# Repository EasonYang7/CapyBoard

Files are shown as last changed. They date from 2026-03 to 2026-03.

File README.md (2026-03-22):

# CapyBoard

Capyboard is a custom designed 80% TKL with custom knobs & OLED screen to fuel the exciting daily workload!

Inspired from the cute Capybara, the keyboard is a cozy comfort to all students studying for exams, and locking in for academics :)

## Features:
- Top & Bottom 3D Modelled Case
- 1x 128x64 OLED Display
- 2x Rotary Knob
- 79x RGB LEDs
- 79x Keys
- KMK Support

## BOM:
- 79x Cherry MX Switches
- 79x SK6812 Mini LEDs
- 79x 1N4148 Diodes
- 1x 128x64 OLED Screen
- 2x 4.7k 0603 Resistors
- 2x EC11E Rotary Encoders
- 1x Seeed Studio Xiao
- 1x Raspberry Pi Pico
- 1x Keycap Set

## Microcontroller
This keyboard supports two microcontroller options:
- Seeed Studio Xiao RP2040 (Main Usage)
- Raspberry Pi Pico (Alternative Usage if Needed)

Both firmware files will be used for seperate input purposes

## Flashing Firmware:

### Step 1 - Install MicroPython
1. Hold BOOTSEL Button on XIAO, and plug in USB-C
2. Download MicroPython .uf2 from https://micropython.org/download/SEEED_XIAO_RP2040/
3. Drag and Drop .uf2 file into RPI-RP2 Drive

### Step 2 - Install KMK
1. Download KMK from https://github.com/KMKfw/kmk_firmware
2. Copy the kmk folder to my XIAO

**Step 3 - Flash Keyboard Firmware**
1. Copy XIAO_code.py to your XIAO and rename it main.py

## Assembly
- Solder components using the schematic as reference
- Install switches onto PCB
- 3D Print the Case
- Use M2 Screws to Assemble the Chassis
- Flash Firmware onto the Keyboard!

## Usage
- Plug USB-C Cable to the Seeed Xiao Studio RP2040
- Keys are Mapped, and can be Modified using KMK!

## Pictures
Schematics:



PCB:




3D Model:


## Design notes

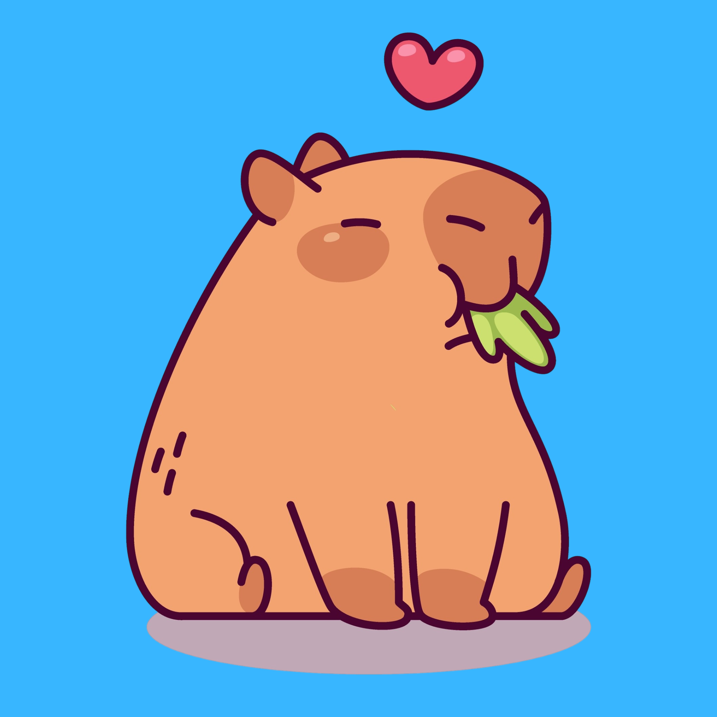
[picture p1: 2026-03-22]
pcb/assets/capybara.png

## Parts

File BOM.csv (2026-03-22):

Component | Quantity | Description | Price (USD) | Link
Seeed Xiao Studio RP2040 | 1 | Microcontroller | 4.68 | https://www.digikey.com/en/products/detail/seeed-technology-co-ltd/102010428/14672129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
Raspberry Pi Pico | 1 | Microcontroller | 4.00 | https://www.digikey.com/en/products/detail/raspberry-pi/SC0915/13624793
Switch | 90 (Cheapest Quantity) | MX Keyboard Switch | Current Price: 20.99 (Original Price: 23.52) | https://www.aliexpress.us/item/3256806239135691.html?curPageLogUid=KsPg7OFSwE63
LEDs | 100 (Cheapest Quantity) | SK6812 MINI-E | 4.33 | https://www.aliexpress.com/item/1005007863635868.html?curPageLogUid=sAzteVQnU8do
Diodes | 100 (Cheapest Quantity) | 1N4148 Diodes | 3.38 | https://www.digikey.com/en/products/detail/onsemi/1N4148/458603
OLED | 1 | 0.96in OLED | Current Price: 1.14 (Original Price: 5.35) | https://www.aliexpress.us/item/3256806076593949.html
Resistors | 10 (Cheapest Quantity) | 4.7k Resistors | 0.06 | https://www.digikey.com/en/products/detail/yageo/RC0603FR-074K7L/727212
Rotary Encoders | 2 | EC11E Rotary Encoders | 8.98 | https://www.digikey.com/en/products/detail/alps-alpine/EC11E09244BS/21721622
Keycap Set | 1 | Capybara Cherry PBT Set | Current Price: 27.12 (Original Price: 63.07) | https://www.aliexpress.us/item/3256809804692169.html?curPageLogUid=72wE0FsKHJUA
PCB | 1 | JLCPCB PCB Assembly | 24.50 (Estimate) | https://jlcpcb.com/

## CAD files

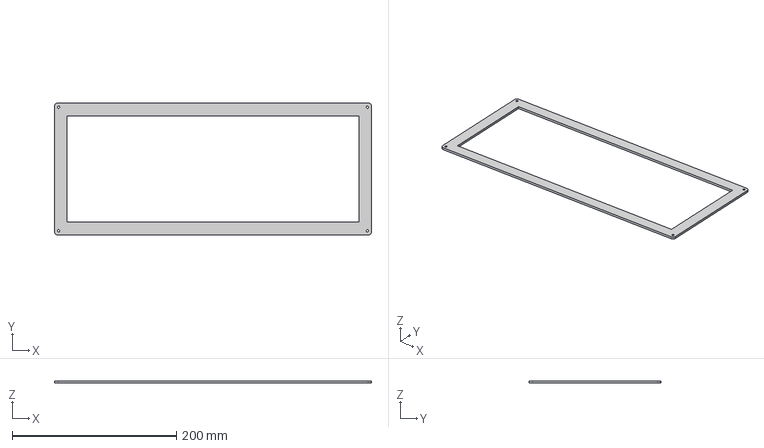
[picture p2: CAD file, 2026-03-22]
cad/CapyBoard Top.step
385.5 x 160.5 x 3.00 mm

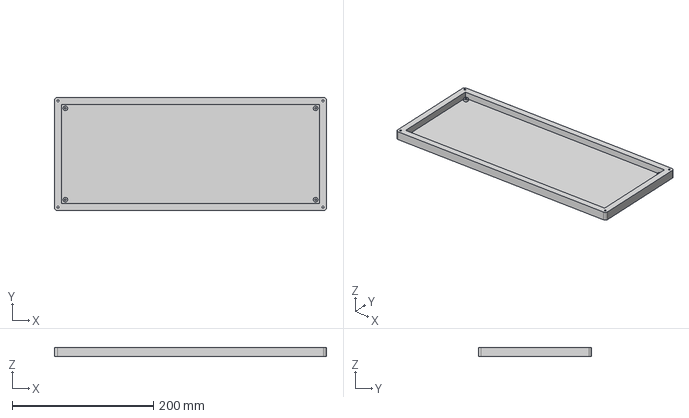
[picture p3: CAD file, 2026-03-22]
cad/CapyBoard Bottom.step
385.5 x 160.5 x 13.0 mm

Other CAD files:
cad/CapyBoard Bottom.f3d
cad/CapyBoard Top.f3d

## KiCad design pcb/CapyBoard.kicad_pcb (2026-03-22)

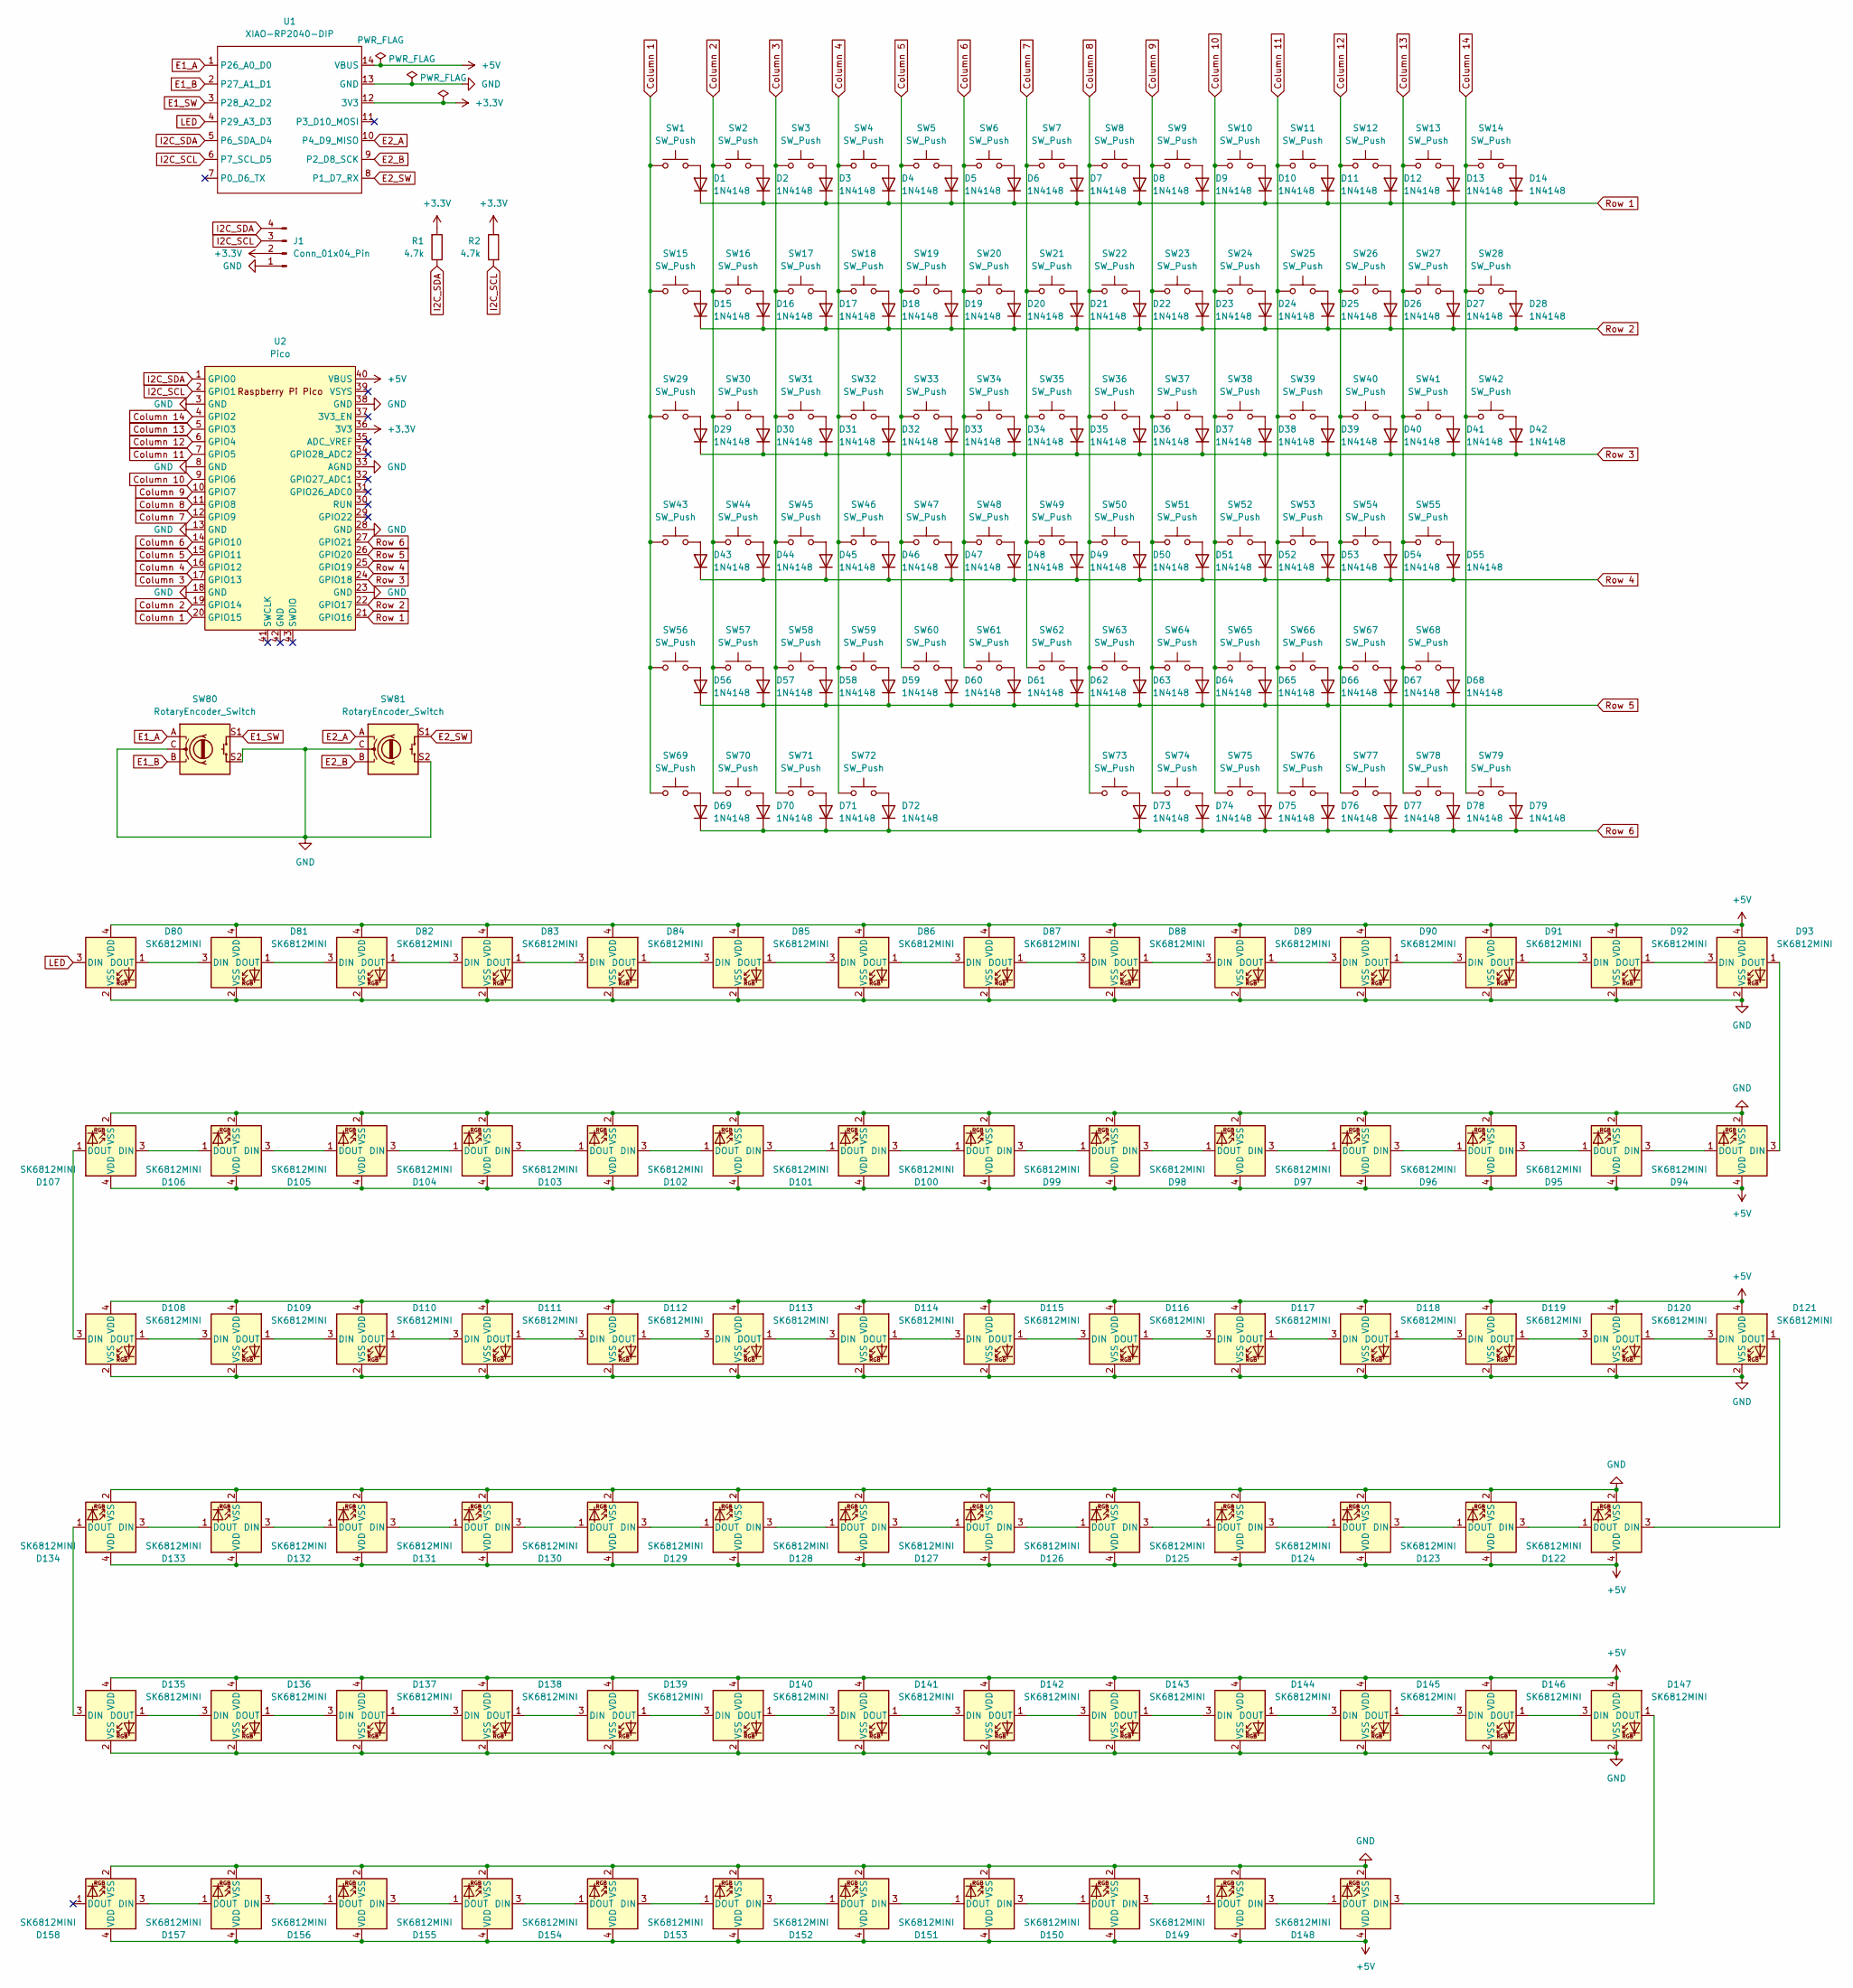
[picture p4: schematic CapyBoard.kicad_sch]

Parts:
D1, D2, D3, D4, D5, D6, D7, D8, D9, D10, D11, D12, D13, D14, D15, D16, D17, D18, D19, D20, D21, D22, D23, D24, D25, D26, D27, D28, D29, D30, D31, D32, D33, D34, D35, D36, D37, D38, D39, D40, D41, D42, D43, D44, D45, D46, D47, D48, D49, D50, D51, D52, D53, D54, D55, D56, D57, D58, D59, D60, D61, D62, D63, D64, D65, D66, D67, D68, D69, D70, D71, D72, D73, D74, D75, D76, D77, D78, D79: 1N4148; D_DO-35_SOD27_P7.62mm_Horizontal
D80, D81, D82, D83, D84, D85, D86, D87, D88, D89, D90, D91, D92, D93, D94, D95, D96, D97, D98, D99, D100, D101, D102, D103, D104, D105, D106, D107, D108, D109, D110, D111, D112, D113, D114, D115, D116, D117, D118, D119, D120, D121, D122, D123, D124, D125, D126, D127, D128, D129, D130, D131, D132, D133, D134, D135, D136, D137, D138, D139, D140, D141, D142, D143, D144, D145, D146, D147, D148, D149, D150, D151, D152, D153, D154, D155, D156, D157, D158: SK6812MINI; LED_SK6812MINI_PLCC4_3.5x3.5mm_P1.75mm
J1: Conn_01x04_Pin; 128x64OLED
R1, R2: 4.7k; R_0603_1608Metric_Pad0.98x0.95mm_HandSolder
SW1, SW2, SW3, SW4, SW5, SW6, SW7, SW8, SW9, SW10, SW11, SW12, SW13, SW14, SW15, SW16, SW17, SW18, SW19, SW20, SW21, SW22, SW23, SW24, SW25, SW26, SW27, SW30, SW31, SW32, SW33, SW34, SW35, SW36, SW37, SW38, SW39, SW40, SW41, SW44, SW45, SW46, SW47, SW48, SW49, SW50, SW51, SW52, SW53, SW54, SW57, SW58, SW59, SW60, SW61, SW62, SW63, SW64, SW65, SW66, SW68, SW77, SW78, SW79: SW_Push; SW_Cherry_MX_1.00u_PCB
SW28: SW_Push; SW_Cherry_MX_2.00u_PCB
SW29, SW42: SW_Push; SW_Cherry_MX_1.50u_PCB
SW43: SW_Push; SW_Cherry_MX_1.75u_PCB
SW55, SW56: SW_Push; SW_Cherry_MX_2.25u_PCB
SW67: SW_Push; SW_Cherry_MX_2.75u_PCB
SW69, SW70, SW71, SW73, SW74, SW75, SW76: SW_Push; SW_Cherry_MX_1.25u_PCB
SW72: SW_Push; SW_Cherry_MX_6.25u_PCB
SW80, SW81: RotaryEncoder_Switch; RotaryEncoder_Alps_EC11E-Switch_Vertical_H20mm_CircularMoun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
U1: XIAO-RP2040-DIP
U2: Pico; RPi_Pico_SMD_TH

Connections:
+3.3V: J1.2, R1.2, R2.1, U1.12 (3V3), U2.36 (3V3)
+5V: D80.4 (VDD), D81.4 (VDD), D82.4 (VDD), D83.4 (VDD), D84.4 (VDD), D85.4 (VDD), D86.4 (VDD), D87.4 (VDD), D88.4 (VDD), D89.4 (VDD), D90.4 (VDD), D91.4 (VDD), D92.4 (VDD), D93.4 (VDD), D94.4 (VDD), D95.4 (VDD), D96.4 (VDD), D97.4 (VDD), D98.4 (VDD), D99.4 (VDD), D100.4 (VDD), D101.4 (VDD), D102.4 (VDD), D103.4 (VDD), D104.4 (VDD), D105.4 (VDD), D106.4 (VDD), D107.4 (VDD), D108.4 (VDD), D109.4 (VDD), D110.4 (VDD), D111.4 (VDD), D112.4 (VDD), D113.4 (VDD), D114.4 (VDD), D115.4 (VDD), D116.4 (VDD), D117.4 (VDD), D118.4 (VDD), D119.4 (VDD), D120.4 (VDD), D121.4 (VDD), D122.4 (VDD), D123.4 (VDD), D124.4 (VDD), D125.4 (VDD), D126.4 (VDD), D127.4 (VDD), D128.4 (VDD), D129.4 (VDD), D130.4 (VDD), D131.4 (VDD), D132.4 (VDD), D133.4 (VDD), D134.4 (VDD), D135.4 (VDD), D136.4 (VDD), D137.4 (VDD), D138.4 (VDD), D139.4 (VDD), D140.4 (VDD), D141.4 (VDD), D142.4 (VDD), D143.4 (VDD), D144.4 (VDD), D145.4 (VDD), D146.4 (VDD), D147.4 (VDD), D148.4 (VDD), D149.4 (VDD), D150.4 (VDD), D151.4 (VDD), D152.4 (VDD), D153.4 (VDD), D154.4 (VDD), D155.4 (VDD), D156.4 (VDD), D157.4 (VDD), D158.4 (VDD), U1.14 (VBUS), U2.40 (VBUS)
Column 1: SW1.1, SW15.1, SW29.1, SW43.1, SW56.1, SW69.1, U2.20 (GPIO15)
Column 2: SW2.1, SW16.1, SW30.1, SW44.1, SW57.1, SW70.1, U2.19 (GPIO14)
Column 3: SW3.1, SW17.1, SW31.1, SW45.1, SW58.1, SW71.1, U2.17 (GPIO13)
Column 4: SW4.1, SW18.1, SW32.1, SW46.1, SW59.1, SW72.1, U2.16 (GPIO12)
Column 5: SW5.1, SW19.1, SW33.1, SW47.1, SW60.1, U2.15 (GPIO11)
Column 6: SW6.1, SW20.1, SW34.1, SW48.1, SW61.1, U2.14 (GPIO10)
Column 7: SW7.1, SW21.1, SW35.1, SW49.1, SW62.1, U2.12 (GPIO9)
Column 8: SW8.1, SW22.1, SW36.1, SW50.1, SW63.1, SW73.1, U2.11 (GPIO8)
Column 9: SW9.1, SW23.1, SW37.1, SW51.1, SW64.1, SW74.1, U2.10 (GPIO7)
Column 10: SW10.1, SW24.1, SW38.1, SW52.1, SW65.1, SW75.1, U2.9 (GPIO6)
Column 11: SW11.1, SW25.1, SW39.1, SW53.1, SW66.1, SW76.1, U2.7 (GPIO5)
Column 12: SW12.1, SW26.1, SW40.1, SW54.1, SW67.1, SW77.1, U2.6 (GPIO4)
Column 13: SW13.1, SW27.1, SW41.1, SW55.1, SW68.1, SW78.1, U2.5 (GPIO3)
Column 14: SW14.1, SW28.1, SW42.1, SW79.1, U2.4 (GPIO2)
E1_A: SW80.A, U1.1 (P26_A0_D0)
E1_B: SW80.B, U1.2 (P27_A1_D1)
E1_SW: SW80.S1, U1.3 (P28_A2_D2)
E2_A: SW81.A, U1.10 (P4_D9_MISO)
E2_B: SW81.B, U1.9 (P2_D8_SCK)
E2_SW: SW81.S1, U1.8 (P1_D7_RX)
GND: D80.2 (VSS), D81.2 (VSS), D82.2 (VSS), D83.2 (VSS), D84.2 (VSS), D85.2 (VSS), D86.2 (VSS), D87.2 (VSS), D88.2 (VSS), D89.2 (VSS), D90.2 (VSS), D91.2 (VSS), D92.2 (VSS), D93.2 (VSS), D94.2 (VSS), D95.2 (VSS), D96.2 (VSS), D97.2 (VSS), D98.2 (VSS), D99.2 (VSS), D100.2 (VSS), D101.2 (VSS), D102.2 (VSS), D103.2 (VSS), D104.2 (VSS), D105.2 (VSS), D106.2 (VSS), D107.2 (VSS), D108.2 (VSS), D109.2 (VSS), D110.2 (VSS), D111.2 (VSS), D112.2 (VSS), D113.2 (VSS), D114.2 (VSS), D115.2 (VSS), D116.2 (VSS), D117.2 (VSS), D118.2 (VSS), D119.2 (VSS), D120.2 (VSS), D121.2 (VSS), D122.2 (VSS), D123.2 (VSS), D124.2 (VSS), D125.2 (VSS), D126.2 (VSS), D127.2 (VSS), D128.2 (VSS), D129.2 (VSS), D130.2 (VSS), D131.2 (VSS), D132.2 (VSS), D133.2 (VSS), D134.2 (VSS), D135.2 (VSS), D136.2 (VSS), D137.2 (VSS), D138.2 (VSS), D139.2 (VSS), D140.2 (VSS), D141.2 (VSS), D142.2 (VSS), D143.2 (VSS), D144.2 (VSS), D145.2 (VSS), D146.2 (VSS), D147.2 (VSS), D148.2 (VSS), D149.2 (VSS), D150.2 (VSS), D151.2 (VSS), D152.2 (VSS), D153.2 (VSS), D154.2 (VSS), D155.2 (VSS), D156.2 (VSS), D157.2 (VSS), D158.2 (VSS), J1.1, SW80.C, SW80.MP, SW80.S2, SW81.C, SW81.MP, SW81.S2, U1.13 (GND), U2.3 (GND), U2.8 (GND), U2.13 (GND), U2.18 (GND), U2.23 (GND), U2.28 (GND), U2.33 (AGND), U2.38 (GND)
I2C_SCL: J1.3, R2.2, U1.6 (P7_SCL_D5), U2.2 (GPIO1)
I2C_SDA: J1.4, R1.1, U1.5 (P6_SDA_D4), U2.1 (GPIO0)
LED: D80.3 (DIN), U1.4 (P29_A3_D3)
unnamed: D1.2 (A), SW1.2
unnamed: D2.2 (A), SW2.2
unnamed: D3.2 (A), SW3.2
unnamed: D4.2 (A), SW4.2
unnamed: D5.2 (A), SW5.2
unnamed: D6.2 (A), SW6.2
unnamed: D7.2 (A), SW7.2
unnamed: D8.2 (A), SW8.2
unnamed: D9.2 (A), SW9.2
unnamed: D10.2 (A), SW10.2
unnamed: D11.2 (A), SW11.2
unnamed: D12.2 (A), SW12.2
unnamed: D13.2 (A), SW13.2
unnamed: D14.2 (A), SW14.2
unnamed: D15.2 (A), SW15.2
unnamed: D16.2 (A), SW16.2
unnamed: D17.2 (A), SW17.2
unnamed: D18.2 (A), SW18.2
unnamed: D19.2 (A), SW19.2
unnamed: D20.2 (A), SW20.2
unnamed: D21.2 (A), SW21.2
unnamed: D22.2 (A), SW22.2
unnamed: D23.2 (A), SW23.2
unnamed: D24.2 (A), SW24.2
unnamed: D25.2 (A), SW25.2
unnamed: D26.2 (A), SW26.2
unnamed: D27.2 (A), SW27.2
unnamed: D28.2 (A), SW28.2
unnamed: D29.2 (A), SW29.2
unnamed: D30.2 (A), SW30.2
unnamed: D31.2 (A), SW31.2
unnamed: D32.2 (A), SW32.2
unnamed: D33.2 (A), SW33.2
unnamed: D34.2 (A), SW34.2
unnamed: D35.2 (A), SW35.2
unnamed: D36.2 (A), SW36.2
unnamed: D37.2 (A), SW37.2
unnamed: D38.2 (A), SW38.2
unnamed: D39.2 (A), SW39.2
unnamed: D40.2 (A), SW40.2
unnamed: D41.2 (A), SW41.2
unnamed: D42.2 (A), SW42.2
unnamed: D43.2 (A), SW43.2
unnamed: D44.2 (A), SW44.2
unnamed: D45.2 (A), SW45.2
unnamed: D46.2 (A), SW46.2
unnamed: D47.2 (A), SW47.2
unnamed: D48.2 (A), SW48.2
unnamed: D49.2 (A), SW49.2
unnamed: D50.2 (A), SW50.2
unnamed: D51.2 (A), SW51.2
unnamed: D52.2 (A), SW52.2
unnamed: D53.2 (A), SW53.2
unnamed: D54.2 (A), SW54.2
unnamed: D55.2 (A), SW55.2
unnamed: D56.2 (A), SW56.2
unnamed: D57.2 (A), SW57.2
unnamed: D58.2 (A), SW58.2
unnamed: D59.2 (A), SW59.2
unnamed: D60.2 (A), SW60.2
unnamed: D61.2 (A), SW61.2
unnamed: D62.2 (A), SW62.2
unnamed: D63.2 (A), SW63.2
unnamed: D64.2 (A), SW64.2
unnamed: D65.2 (A), SW65.2
unnamed: D66.2 (A), SW66.2
unnamed: D67.2 (A), SW67.2
unnamed: D68.2 (A), SW68.2
unnamed: D69.2 (A), SW69.2
unnamed: D70.2 (A), SW70.2
unnamed: D71.2 (A), SW71.2
unnamed: D72.2 (A), SW72.2
unnamed: D73.2 (A), SW73.2
unnamed: D74.2 (A), SW74.2
unnamed: D75.2 (A), SW75.2
unnamed: D76.2 (A), SW76.2
unnamed: D77.2 (A), SW77.2
unnamed: D78.2 (A), SW78.2
unnamed: D79.2 (A), SW79.2
unnamed: D80.1 (DOUT), D81.3 (DIN)
unnamed: D81.1 (DOUT), D82.3 (DIN)
unnamed: D82.1 (DOUT), D83.3 (DIN)
unnamed: D83.1 (DOUT), D84.3 (DIN)
unnamed: D84.1 (DOUT), D85.3 (DIN)
unnamed: D85.1 (DOUT), D86.3 (DIN)
unnamed: D86.1 (DOUT), D87.3 (DIN)
unnamed: D87.1 (DOUT), D88.3 (DIN)
unnamed: D88.1 (DOUT), D89.3 (DIN)
unnamed: D89.1 (DOUT), D90.3 (DIN)
unnamed: D90.1 (DOUT), D91.3 (DIN)
unnamed: D91.1 (DOUT), D92.3 (DIN)
unnamed: D92.1 (DOUT), D93.3 (DIN)
unnamed: D93.1 (DOUT), D94.3 (DIN)
unnamed: D94.1 (DOUT), D95.3 (DIN)
unnamed: D95.1 (DOUT), D96.3 (DIN)
unnamed: D96.1 (DOUT), D97.3 (DIN)
unnamed: D97.1 (DOUT), D98.3 (DIN)
unnamed: D98.1 (DOUT), D99.3 (DIN)
unnamed: D99.1 (DOUT), D100.3 (DIN)
unnamed: D100.1 (DOUT), D101.3 (DIN)
unnamed: D101.1 (DOUT), D102.3 (DIN)
unnamed: D102.1 (DOUT), D103.3 (DIN)
unnamed: D103.1 (DOUT), D104.3 (DIN)
unnamed: D104.1 (DOUT), D105.3 (DIN)
unnamed: D105.1 (DOUT), D106.3 (DIN)
unnamed: D106.1 (DOUT), D107.3 (DIN)
unnamed: D107.1 (DOUT), D108.3 (DIN)
unnamed: D108.1 (DOUT), D109.3 (DIN)
unnamed: D109.1 (DOUT), D110.3 (DIN)
unnamed: D110.1 (DOUT), D111.3 (DIN)
unnamed: D111.1 (DOUT), D112.3 (DIN)
unnamed: D112.1 (DOUT), D113.3 (DIN)
unnamed: D113.1 (DOUT), D114.3 (DIN)
unnamed: D114.1 (DOUT), D115.3 (DIN)
unnamed: D115.1 (DOUT), D116.3 (DIN)
unnamed: D116.1 (DOUT), D117.3 (DIN)
unnamed: D117.1 (DOUT), D118.3 (DIN)
unnamed: D118.1 (DOUT), D119.3 (DIN)
unnamed: D119.1 (DOUT), D120.3 (DIN)
unnamed: D120.1 (DOUT), D121.3 (DIN)
unnamed: D121.1 (DOUT), D122.3 (DIN)
unnamed: D122.1 (DOUT), D123.3 (DIN)
unnamed: D123.1 (DOUT), D124.3 (DIN)
unnamed: D124.1 (DOUT), D125.3 (DIN)
unnamed: D125.1 (DOUT), D126.3 (DIN)
unnamed: D126.1 (DOUT), D127.3 (DIN)
unnamed: D127.1 (DOUT), D128.3 (DIN)
unnamed: D128.1 (DOUT), D129.3 (DIN)
unnamed: D129.1 (DOUT), D130.3 (DIN)
unnamed: D130.1 (DOUT), D131.3 (DIN)
unnamed: D131.1 (DOUT), D132.3 (DIN)
unnamed: D132.1 (DOUT), D133.3 (DIN)
unnamed: D133.1 (DOUT), D134.3 (DIN)
unnamed: D134.1 (DOUT), D135.3 (DIN)
unnamed: D135.1 (DOUT), D136.3 (DIN)
unnamed: D136.1 (DOUT), D137.3 (DIN)
unnamed: D137.1 (DOUT), D138.3 (DIN)
unnamed: D138.1 (DOUT), D139.3 (DIN)
unnamed: D139.1 (DOUT), D140.3 (DIN)
unnamed: D140.1 (DOUT), D141.3 (DIN)
unnamed: D141.1 (DOUT), D142.3 (DIN)
unnamed: D142.1 (DOUT), D143.3 (DIN)
unnamed: D143.1 (DOUT), D144.3 (DIN)
unnamed: D144.1 (DOUT), D145.3 (DIN)
unnamed: D145.1 (DOUT), D146.3 (DIN)
unnamed: D146.1 (DOUT), D147.3 (DIN)
unnamed: D147.1 (DOUT), D148.3 (DIN)
unnamed: D148.1 (DOUT), D149.3 (DIN)
unnamed: D149.1 (DOUT), D150.3 (DIN)
unnamed: D150.1 (DOUT), D151.3 (DIN)
unnamed: D151.1 (DOUT), D152.3 (DIN)
unnamed: D152.1 (DOUT), D153.3 (DIN)
unnamed: D153.1 (DOUT), D154.3 (DIN)
unnamed: D154.1 (DOUT), D155.3 (DIN)
unnamed: D155.1 (DOUT), D156.3 (DIN)
unnamed: D156.1 (DOUT), D157.3 (DIN)
unnamed: D157.1 (DOUT), D158.3 (DIN)
Row 1: D1.1 (K), D2.1 (K), D3.1 (K), D4.1 (K), D5.1 (K), D6.1 (K), D7.1 (K), D8.1 (K), D9.1 (K), D10.1 (K), D11.1 (K), D12.1 (K), D13.1 (K), D14.1 (K), U2.21 (GPIO16)
Row 2: D15.1 (K), D16.1 (K), D17.1 (K), D18.1 (K), D19.1 (K), D20.1 (K), D21.1 (K), D22.1 (K), D23.1 (K), D24.1 (K), D25.1 (K), D26.1 (K), D27.1 (K), D28.1 (K), U2.22 (GPIO17)
Row 3: D29.1 (K), D30.1 (K), D31.1 (K), D32.1 (K), D33.1 (K), D34.1 (K), D35.1 (K), D36.1 (K), D37.1 (K), D38.1 (K), D39.1 (K), D40.1 (K), D41.1 (K), D42.1 (K), U2.24 (GPIO18)
Row 4: D43.1 (K), D44.1 (K), D45.1 (K), D46.1 (K), D47.1 (K), D48.1 (K), D49.1 (K), D50.1 (K), D51.1 (K), D52.1 (K), D53.1 (K), D54.1 (K), D55.1 (K), U2.25 (GPIO19)
Row 5: D56.1 (K), D57.1 (K), D58.1 (K), D59.1 (K), D60.1 (K), D61.1 (K), D62.1 (K), D63.1 (K), D64.1 (K), D65.1 (K), D66.1 (K), D67.1 (K), D68.1 (K), U2.26 (GPIO20)
Row 6: D69.1 (K), D70.1 (K), D71.1 (K), D72.1 (K), D73.1 (K), D74.1 (K), D75.1 (K), D76.1 (K), D77.1 (K), D78.1 (K), D79.1 (K), U2.27 (GPIO21)

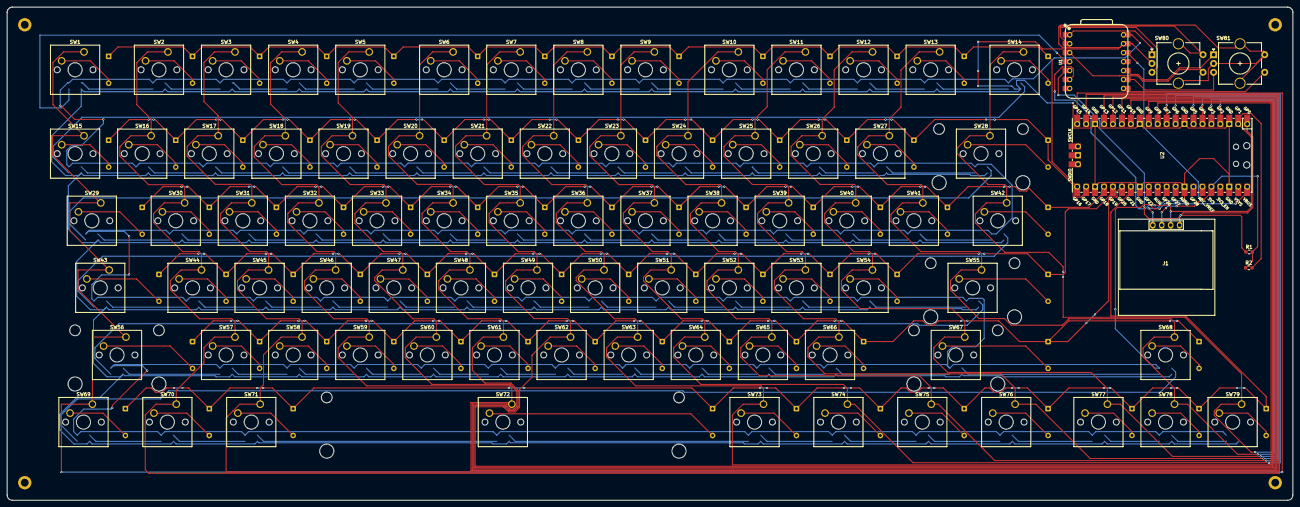
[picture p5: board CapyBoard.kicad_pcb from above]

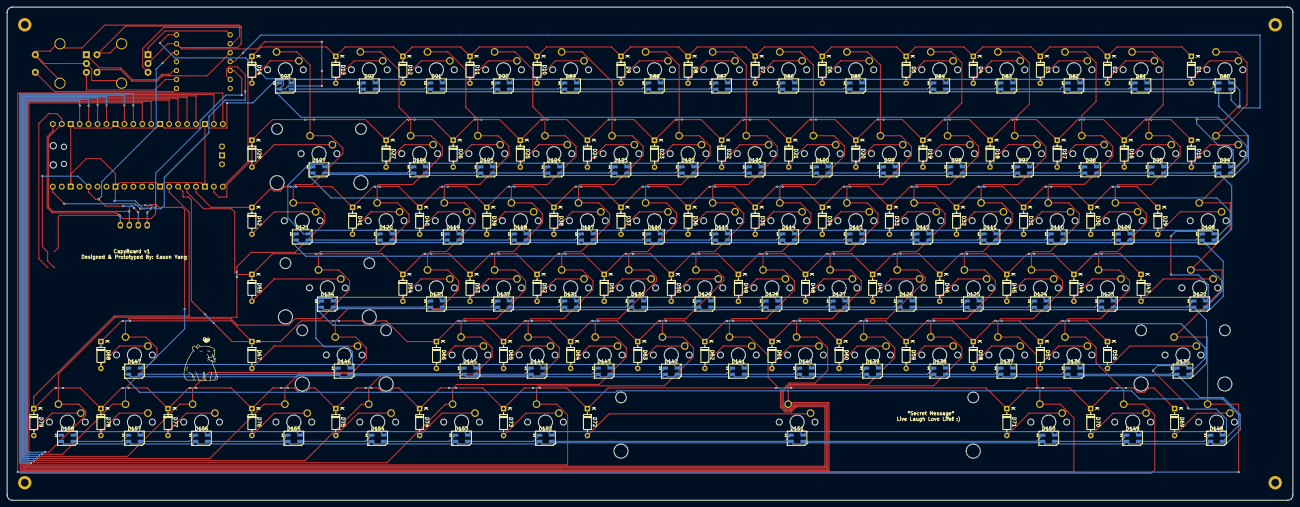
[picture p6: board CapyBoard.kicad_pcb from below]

Board: 2 copper layers, 365.0 x 140.0 mm, 244 parts (158 on the bottom side), 189 nets.

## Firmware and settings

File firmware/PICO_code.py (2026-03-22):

# CapyBoard — Pico Firmware (code.py)

import board
from kmk.kmk_keyboard import KMKKeyboard
from kmk.keys import KC
from kmk.scanners import DiodeOrientation
from kmk.modules.layers import Layers
from kmk.modules.split import Split, SplitType, SplitSide
from kmk.extensions.media_keys import MediaKeys

keyboard = KMKKeyboard()

# Split configuration
split = Split(
    split_type=SplitType.I2C,
    split_side=SplitSide.RIGHT,
    data_pin=board.GP0,  
    data_pin2=board.GP1,   
)

# Column pins (GPIO2-GPIO15)
keyboard.col_pins = (
    board.GP15,
    board.GP14, 
    board.GP13,  
    board.GP12, 
    board.GP11,  
    board.GP10, 
    board.GP9,  
    board.GP8,  
    board.GP7,
    board.GP6,  
    board.GP5, 
    board.GP4,  
    board.GP3,  
    board.GP2,  
)

# ─── Row pins (GPIO16-GPIO21)
keyboard.row_pins = (
    board.GP16, 
    board.GP17,  
    board.GP18, 
    board.GP19, 
    board.GP20, 
    board.GP21,  
)

keyboard.diode_orientation = DiodeOrientation.COL2ROW

# Modules
layers = Layers()
media_keys = MediaKeys()
keyboard.modules = [split, layers, media_keys]

# Keymap
_______ = KC.TRNS
XXXXXXX = KC.NO

keyboard.keymap = [
    # Layer 0 Base QWERTY
    [
        KC.ESC,   KC.N1,   KC.N2,   KC.N3,   KC.N4,   KC.N5,   KC.N6,   KC.N7,   KC.N8,   KC.N9,   KC.N0,   KC.MINS, KC.EQL,  KC.BSPC,
        KC.TAB,   KC.Q,    KC.W,    KC.E,    KC.R,    KC.T,    KC.Y,    KC.U,    KC.I,    KC.O,    KC.P,    KC.LBRC, KC.RBRC, KC.BSLS,
        KC.CAPS,  KC.A,    KC.S,    KC.D,    KC.F,    KC.G,    KC.H,    KC.J,    KC.K,    KC.L,    KC.SCLN, KC.QUOT, XXXXXXX, KC.ENT,
        KC.LSFT,  KC.Z,    KC.X,    KC.C,    KC.V,    KC.B,    KC.N,    KC.M,    KC.COMM, KC.DOT,  KC.SLSH, XXXXXXX, XXXXXXX, KC.RSFT,
        KC.LCTL,  KC.LGUI, KC.LALT, XXXXXXX, XXXXXXX, XXXXXXX, KC.SPC,  XXXXXXX, XXXXXXX, XXXXXXX, KC.RALT, KC.APP,  XXXXXXX, KC.RCTL,
        KC.MO(1), KC.F1,   KC.F2,   KC.F3,   XXXXXXX, KC.F4,   KC.F5,   KC.F6,   KC.F7,   KC.F8,   KC.F9,   KC.F10,  KC.F11,  KC.F12,
    ],
    # Layer 1 Function
    [
        KC.GRV,   KC.F1,   KC.F2,   KC.F3,   KC.F4,   KC.F5,   KC.F6,   KC.F7,   KC.F8,   KC.F9,   KC.F10,  KC.F11,  KC.F12,  KC.DEL,
        _______,  _______, KC.UP,   _______, _______, _______, _______, _______, _______, _______, _______, _______, _______, _______,
        _______,  KC.LEFT, KC.DOWN, KC.RGHT, _______, _______, _______, _______, _______, _______, _______, _______, _______, _______,
        _______,  _______, _______, _______, _______, _______, _______, _______, _______, _______, _______, _______, _______, _______,
        _______,  _______, _______, _______, _______, _______, _______, _______, _______, _______, _______, _______, _______, _______,
        _______,  _______, _______, _______, _______, _______, _______, _______, _______, _______, _______, _______, _______, _______,
    ],
    # Layer 2 Media
    [
        _______, KC.MUTE, KC.VOLD, KC.VOLU, KC.MPRV, KC.MPLY, KC.MNXT, _______, _______, _______, _______, _______, _______, _______,
        _______, _______, _______, _______, _______, _______, _______, _______, _______, _______, _______, _______, _______, _______,
        _______, _______, _______, _______, _______, _______, _______, _______, _______, _______, _______, _______, _______, _______,
        _______, _______, _______, _______, _______, _______, _______, _______, _______, _______, _______, _______, _______, _______,
        _______, _______, _______, _______, _______, _______, _______, _______, _______, _______, _______, _______, _______, _______,
        _______, _______, _______, _______, _______, _______, _______, _______, _______, _______, _______, _______, _______, _______,
    ],
]

if __name__ == '__main__':
    keyboard.go()

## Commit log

2026-03-22 Correct diode model from IN4148 to 1N4148
2026-03-22 fixed gerber files
    [BOM.csv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]
2026-03-22 modified the README, added new CAD files
    [BOM.csv, CapyBoard Bottom.f3d, CapyBoard Top.f3d]
2026-03-22 fix OLED quoting error in BOM.csv
    [BOM.csv]
2026-03-22 gerbers modification
    [CapyBoard-B_Cu.gbr, CapyBoard-B_Mask.gbr, CapyBoard-B_Paste.gbr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]
2026-03-22 modified the README, and changed gerbers!
2026-03-22 Changed README files
    [BOM.csv]
2026-03-22 modified gerbers
    [BOM.csv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]
2026-03-22 Update price and link for Seeed Xiao Studio RP2040
    Updated the price of Seeed Xiao Studio RP2040 and modified its link.
    [BOM.csv]
2026-03-22 Update Switch price and link in BOM.csv
    Updated the price and link for the MX Keyboard Switch.
    [BOM.csv]
2026-03-22 Update switch quantity and add new components
    [BOM.csv]
2026-03-22 Update OLED entry with current price and link
    Updated OLED price and link in BOM.
    [BOM.csv]
2026-03-22 Fix Resistors entry format in BOM.csv
    Updated the Resistors entry to clarify quantity and price format.
    [BOM.csv]
2026-03-22 Update prices for components in BOM.csv
    Updated the current prices and original prices for the Switch, LEDs, and OLED components in the BOM.
    [BOM.csv]
2026-03-22 Update component prices and links in BOM.csv
    Updated prices and links for components in BOM.
    [BOM.csv]
2026-03-22 Update OLED entry with new price and link
    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
    [BOM.csv]
